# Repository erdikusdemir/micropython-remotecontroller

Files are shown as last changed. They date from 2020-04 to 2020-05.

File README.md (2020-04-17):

# micropython-remotecontroller
ESP8266 based smart remote controller. Code works on micropython.  
The version with the C++: https://github.com/erdikusdemir/smarthome-wifi-remote  

# DESCRIPTION 

Portable remote controller to control smart home devices over MQTT protocol. It is based on micropython uploaded ESP8266 with OLED LCD and rotary encoder.
Remote can control switches, dimmers, fans, and temperature controllers.

The remote controller communicates with Node-Red flow by MQTT JSON messages. Node-Red flow converts the signals from both remote and HA side and makes implementation easier. Items you would like to control by remote can be edited by "config file" function. Arduino sketch only configures Wifi and MQTT settings. All the item information are called at the initialization stage of the remote.

Wemos kill its power after 15 secs of idle time. Thus, power consumption of the remote is zero when it is not used. 

Hardware is consist of;
1. Wemos D1 mini Pro,
2. A clickable rotary encoder,
3. 0.96" I2C 128x64 OLED display,
4. Wemos battery shield,
5. LIPO battery,
6. 3D printed enclosure (under progress),  
7. TPS27081ADDCR load switch,  
8. 2222A NPN transistor,  
9. 330, 1 k, and 1 MOhm resistors.  

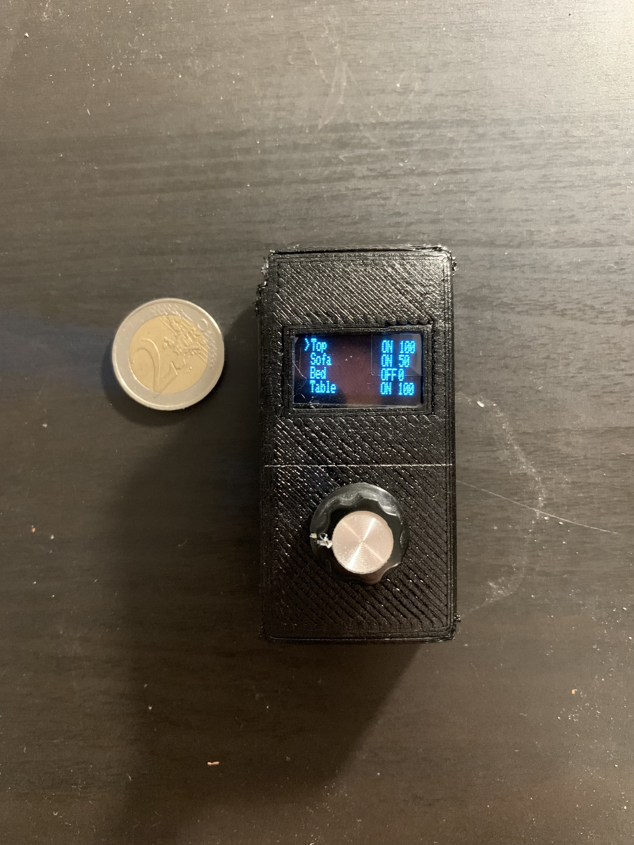
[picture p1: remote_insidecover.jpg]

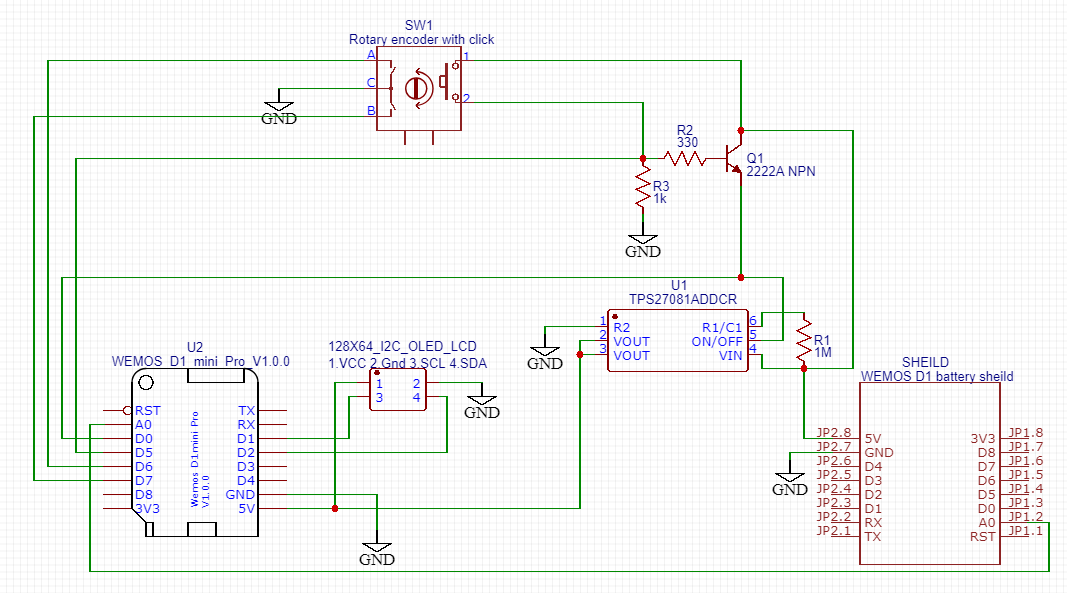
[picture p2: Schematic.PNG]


# Micropython installation and code upload:  
1. Install python core from here https://www.python.org/downloads/  
2. Download esptool from here https://github.com/espressif/esptool/releases and unzip in a folder  
3. Download esp8266 micropython firmware from here https://micropython.org/download/esp8266/ (you can pick the recent stable release)  
4. open console in your operating system. for windows: cmd
5. go to the directery of esptool.py  for windows example: cd C:\Users\"user"\Desktop\esptool-master
6. connect the chip to the PC  
7. run "python esptool.py --chip esp8266 erase_flash" (COM port will be showed on the screen. Please note the COM port for the next step(s))  
8. after erase completed run flash code "python esptool.py --port COM7 --baud 460800 write_flash --flash_size=4MB 0 C:\Users\"user"\esp8266-2020.bin" (Don't forget to change your COM port and the full directory of the micropython firmware.)  
9. Edit the secrets.json file according to your credentials and save it  
10. Now we can upload the code. Download "uPyloader" from here https://github.com/BetaRavener/uPyLoader/releases  
11. Run the program and connect to your device. After the first connection a popup window will show up. Say ok and go to File -> Init transfer files. After program sends two files you should see the programs inside the chip  
12. Go to File -> Navigate and select the project folder  
13. On the left side you should see the project files. Select the files with .py extention and the "secrets.json" and press transfer. 
14. After transfer completed hard reset the device and you should good to go  
15. Bravo!  

# Instructions:  
1. Follow the schematic and build the hardware,  
2.1. Modify the secret.json file according to your credentials,  
2.2. Copy the files into the micropython ESP8266,  
3.1. Copy NodeRed flow into your NodeRed server,  
3.2. Configure your HA and MQTT servers,  
3.3. Configure your items by editing "config file" function,  
(id: order in your OLED screen, HAid: id name of item you want to control, type: switch(0), dimmer(1), or temperature controller(2))  
4.4. Deploy the node and everything should works.  

# To do list:
1. ESP chip being very slow to connect to the wifi. This needs to be fasten up somehow. Chip develops an issue when erasing the settings.  
3. Case design needs to be finished.

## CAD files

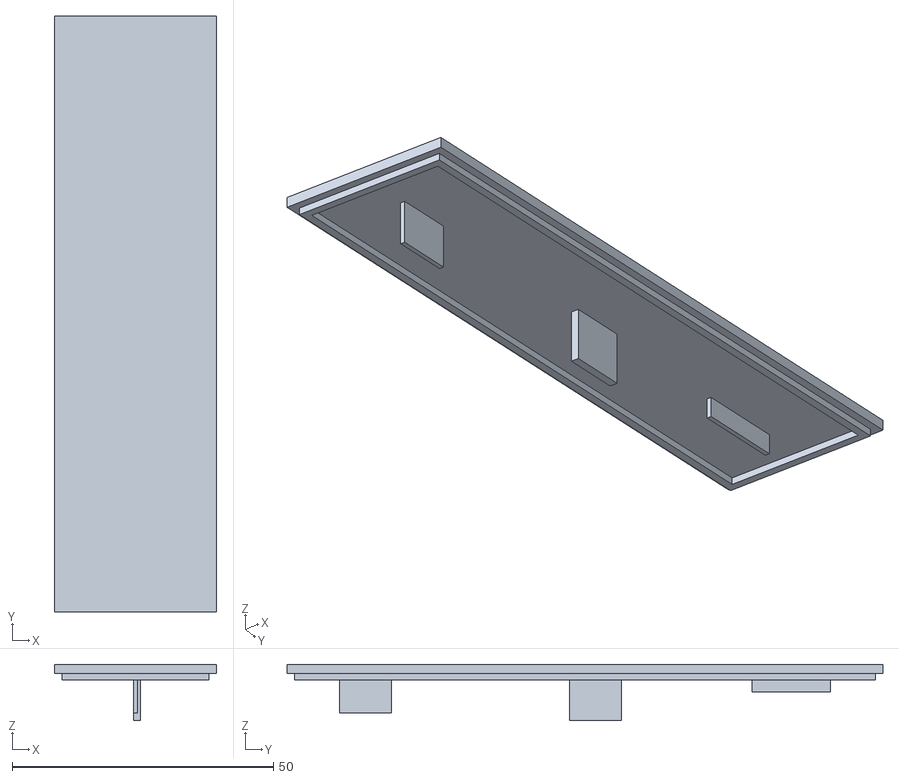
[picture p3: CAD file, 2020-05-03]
case/cover.stl
31.0 x 114.0 x 10.8

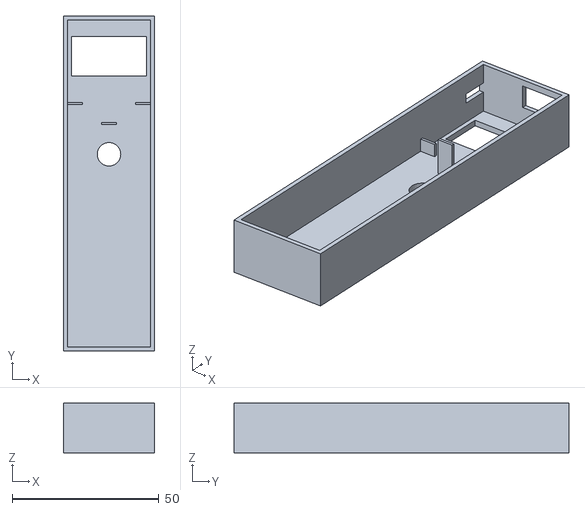
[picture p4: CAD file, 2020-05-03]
case/case.stl
31.0 x 114.0 x 17.0

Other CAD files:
case/remotecase.f3d

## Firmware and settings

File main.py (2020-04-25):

# -----------------------------------------Libraries--------------------------------------------------------------------
import machine
from machine import Pin, I2C, ADC, Timer
import utime
import ssd1306
import network
import ujson
from simple import MQTTClient

# -----------------------------------------Parameter Init---------------------------------------------------------------

print(utime.ticks_ms())
wlan = network.WLAN(network.STA_IF)
killswitch = Pin(16, Pin.OUT)  # kill switch
killswitch.value(1)
oldencdata = 0b0000
encdata = 0b0000
debouncetime = 150
lastbouncetime = 0
updatescreen = 1
dispcursor = 0
pnr = 0

Menu0 = ["id1", "id2", "id3", "id4"]
Value0 = ["off", "off", "0", "20"]
Value1 = ["0", "10", "22", "30"]
datatype = [0, 1, 2, 0]
youkilledme = 0
mqttisready = 0

# -------------------------------------------Read the Secrets.json------------------------------------------------------
#now this part is in boot.py
"""with open('secrets.json', 'r') as openfile:
    # file includes   "devicename", "SSID", "SSIDpass", "StaticIP", "mqttserver", "mqttusername", "mqttpass",
    # "topicpub", "topicsub",
    secrets = ujson.load(openfile)"""
# --------------------------------------------MQTT connection-----------------------------------------------------------
def mqttpublisher():
    global mqttobject
    initialmsg = {}
    initialmsg["id"] = 99
    initialmsgjson = ujson.dumps(initialmsg)
    mqttobject.publish(secrets["topicpub"], initialmsgjson)


def mqttconfig(v):
    global mqttobject, mqttisready
    if wlan.isconnected():
        #mqttconn.deinit()
        mqttobject = MQTTClient(secrets["devicename"], secrets["mqttserver"], port=1883, user=secrets["mqttusername"],
                                password=secrets["mqttpass"])
        mqttobject.set_callback(mqttcallback)
        mqttobject.connect()
        mqttobject.subscribe(secrets["topicsub"])
        mqttpublisher()
        #mqttconn.init(period=150, mode=Timer.PERIODIC, callback=newmsg)
        mqttisready = 2

def mqttcallback(topic, msg):
    global updatescreen
    rcvmsg = ujson.loads(msg)
    try:
        Value0[rcvmsg["id"]] = rcvmsg["value0"]
        Value1[rcvmsg["id"]] = rcvmsg["value1"]
        if "name" in rcvmsg:
           Menu0[rcvmsg["id"]] = rcvmsg["name"]
           datatype[rcvmsg["id"]] = rcvmsg["type"]
    except:  # this is a new line
        Value0.append(rcvmsg["value0"])
        Value1.append(rcvmsg["value1"])
        Menu0.append(rcvmsg["name"])
        datatype.append(rcvmsg["type"])
    updatescreen = 1



def newmsg(v):
    global mqttobject
    mqttobject.check_msg()


# -------------------------------------------WIFI connection-----------------------------------------------------------
#now this part is in boot.py
"""wlan = network.WLAN(network.STA_IF)
if not wlan.isconnected():
    wlan.active(True)
    #wlan.scan()
    wlan.ifconfig(('192.168.1.59', '255.255.255.0', '192.168.1.1', '192.168.1.1'))
    wlan.connect(secrets["SSID"], secrets["SSIDpass"])
    #mqttconn = Timer(2)
    #mqttconn.init(mode=Timer.PERIODIC, period=200, callback=mqttconfig)  # one shot firing after 1000ms
"""
# ------------------------------------------Functions-------------------------------------------------------------------


def dispcursorupdate(incdec):
    global dispcursor, pnr
    if encbut.value() == 0:
        dispcursor = dispcursor + incdec
    elif datatype[dispcursor] == 1:  # set dimmer
        Value1[dispcursor] = str(int(Value1[dispcursor]) + 10 * incdec)
        pnr = 1
        if int(Value1[dispcursor]) < 0:
            Value1[dispcursor] = "0"
        if int(Value1[dispcursor]) > 100:
            Value1[dispcursor] = "100"
        updatemsg = {"id": dispcursor, "value0": Value0[dispcursor], "value1": Value1[dispcursor]}
        updatemsgjson = ujson.dumps(updatemsg)
        mqttobject.publish(secrets["topicpub"], updatemsgjson)
    elif datatype[dispcursor] == 2:  # set temp
        Value1[dispcursor] = str(int(Value1[dispcursor]) + incdec)  # --------------------------bir sender buraya
        pnr = 1
        if int(Value1[dispcursor]) < 18:
            Value1[dispcursor] = "18"
        if int(Value1[dispcursor]) > 30:
            Value1[dispcursor] = "30"
        updatemsg = {"id": dispcursor, "value0": Value0[dispcursor], "value1": Value1[dispcursor]}
        updatemsgjson = ujson.dumps(updatemsg)
        mqttobject.publish(secrets["topicpub"], updatemsgjson)


def encmove(v):
    irq_state = machine.disable_irq()
    global value, encdata, oldencdata, oled, dispcursor, updatescreen, ticktock
    encdata = (encA.value() << 1) | encB.value()
    if ((oldencdata | encdata) == 0b0001) or ((oldencdata | encdata) == 0b1110):  # CW turn.
        dispcursorupdate(1)
    elif ((oldencdata | encdata) == 0b0100) or ((oldencdata | encdata) == 0b1011):  # CCW turn.
        dispcursorupdate(-1)
    oldencdata = encdata << 2
    machine.enable_irq(irq_state)
    updatescreen = 1
    ticktock = utime.ticks_ms()
    #killme.init(period=15000, mode=Timer.ONE_SHOT, callback=shutdown)


def encbutprss(a):
    global debouncetime, lastbouncetime, updatescreen, dispcursor, pnr, ticktock
    irq_state = machine.disable_irq()
    now = utime.ticks_ms()
    if now - lastbouncetime > debouncetime and pnr == 0:

        ticktock = utime.ticks_ms()
        #killme.init(period=15000, mode=Timer.ONE_SHOT, callback=shutdown)
        if Value0[dispcursor] == "off":
            Value0[dispcursor] = "on"
            if datatype[dispcursor] != 2:
                Value1[dispcursor] = "100"
        else:
            Value0[dispcursor] = "off"
            if datatype[dispcursor] != 2:
                Value1[dispcursor] = "0"
        updatemsg = {"id": dispcursor, "value0": Value0[dispcursor], "value1": Value1[dispcursor]}
        updatemsgjson = ujson.dumps(updatemsg)
        mqttobject.publish(secrets["topicpub"], updatemsgjson)
    pnr = 0
    lastbouncetime = now
    updatescreen = 1
    machine.enable_irq(irq_state)


def screenhandler(v):  # lasts 78 ms
    global dispcursor, updatescreen, SSID, mqttobject, screentimer
    if updatescreen:
        if dispcursor <= -1:
            dispcursor = -1
            oled.text("Battery:", 0, 0)
            batlvl = int(((pot.read() - 0) / (960 - 0)) * (100 - 0) + 0)
            oled.text(str(batlvl), 64, 0)
            oled.text("SSID:", 0, 10)
            oled.text(secrets["SSID"], 38, 10)
            oled.text("IP:", 0, 20)
            wifispec = wlan.ifconfig()
            oled.text(wifispec[0], 24, 20)
            oled.text("MQTT: ", 0, 30)
            oled.text(secrets["mqttserver"], 0, 40)
        else:
            if dispcursor > len(Menu0) - 1:
                dispcursor = len(Menu0) - 1
            oled.text(">", 0, (dispcursor % 6) * 10)
            if dispcursor // 6 < (len(Menu0) - 1) // 6:
                rmax = (dispcursor // 6 + 1) * 6
            else:
                rmax = len(Menu0)
            for i in range((dispcursor // 6) * 6, rmax):
                oled.text(Menu0[i], 8, (i % 6) * 10)
                oled.text(str(Value0[i]), 80, (i % 6) * 10)
                oled.text(str(Value1[i]), 105, (i % 6) * 10)
        oled.show()  # lasts 70 ms
        oled.fill(0)
        updatescreen = 0
        screentimer = utime.ticks_ms()


def shutdown(v):
    global youkilledme
    killswitch.value(0)
    print("goodby cruel world")
    youkilledme = 1


# ----------------------------------------------Tickers-----------------------------------------------------------------

#fps = Timer(1)
#fps.init(period=150, mode=Timer.PERIODIC, callback=screenhandler)
# timer2: mqttconn
#killme = Timer(3)
#killme.init(period=15000, mode=Timer.ONE_SHOT, callback=shutdown)

# ----------------------------------------------IO Setup----------------------------------------------------------------
i2c = I2C(-1, scl=Pin(5), sda=Pin(4))  # Oled screen
oled_width = 128
oled_height = 64
oled = ssd1306.SSD1306_I2C(oled_width, oled_height, i2c)
pot = ADC(0)

encA = Pin(12, Pin.IN, Pin.PULL_UP)#create encoder
encA.irq(trigger=Pin.IRQ_RISING | Pin.IRQ_FALLING, handler=encmove)
encB = Pin(13, Pin.IN, Pin.PULL_UP)
encB.irq(trigger=Pin.IRQ_RISING | Pin.IRQ_FALLING, handler=encmove)
encbut = Pin(14, Pin.IN)
encbut.irq(trigger=Pin.IRQ_FALLING, handler=encbutprss)
#----------------------------------------------Fake timers -------------------------------------------------
ticktock = screentimer = mqttchecker = utime.ticks_ms()

def main():
    global screentimer, mqttchecker, ticktock, mqttisready
    while True:
        if (utime.ticks_ms() - ticktock > 15000) and youkilledme == 0:
            shutdown(0)
        if (utime.ticks_ms() - screentimer > 150):
            screenhandler(0)
            screentimer = utime.ticks_ms()
            #newmsg(0)

        if mqttisready == 0 and wlan.isconnected():
            mqttisready = 1
        elif mqttisready == 1:
            mqttconfig(0)
        elif mqttisready == 2:
            mqttobject.check_msg()
            #mqttisready = 3
        elif mqttisready == 3 and (utime.ticks_ms() - mqttchecker > 150):
            print(utime.ticks_ms())
            while mqttobject.check_msg():
                pass
            mqttchecker = utime.ticks_ms()
        machine.idle()


    # ---------------------------------------------------Main Loop-----------------------------------------------------------
if __name__ == '__main__':
    main()
    #pass


# -------------------------------------------------End of Main Loop------------------------------------------------------

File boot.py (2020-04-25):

# This file is executed on every boot (including wake-boot from deepsleep)
#import esp
#esp.osdebug(None)
import uos, machine
#uos.dupterm(None, 1) # disable REPL on UART(0)
import gc
#import webrepl
#webrepl.start()
gc.collect()
import ujson
with open('secrets.json', 'r') as openfile:
    # file includes   "devicename", "SSID", "SSIDpass", "StaticIP", "mqttserver", "mqttusername", "mqttpass",
    # "topicpub", "topicsub",
    secrets = ujson.load(openfile)
import network
network.WLAN(network.STA_IF).active(False)  # WiFi station interface
#network.WLAN(network.AP_IF).active(False)  # access-point interface
wlan = network.WLAN(network.STA_IF)
if not wlan.isconnected():
    wlan.active(True)
    #wlan.scan()
    wlan.ifconfig((secrets["StaticIP"], '255.255.255.0', secrets["RouterIP"], secrets["RouterIP"]))
    wlan.connect(secrets["SSID"], secrets["SSIDpass"])

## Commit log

2020-04-17 Alpha 0.1
    This is the first commit. Code is functional with a major missing parts.
    Currently, controller can download the data from the server bur upload part has not implemented yet.
    [main.py]
2020-04-17 sending mqtt mesages is completed.
    Now code is properly working.
    Temperature objects needs to be checked. Nodered cannot communicate properly with HA.
2020-04-25 better boot sequance and solved crash problem
    Timers are beautiful resources but apperantly they causes WDT reset for the chip. Currently, I could't find a good way to disable ISR when Soft Reset command arrived.
    Boot sequance is faster now. WIFI connection is done inside the boot.py now.
    [boot.py, main.py]
2020-05-03 new case design.
    New case design is longer than it was which helps you to hold the controller better.
    [case.stl, cover.stl, remotecase.f3d]
